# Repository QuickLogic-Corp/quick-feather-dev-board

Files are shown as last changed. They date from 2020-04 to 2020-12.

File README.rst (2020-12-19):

==============================
QuickFeather Development Board
==============================

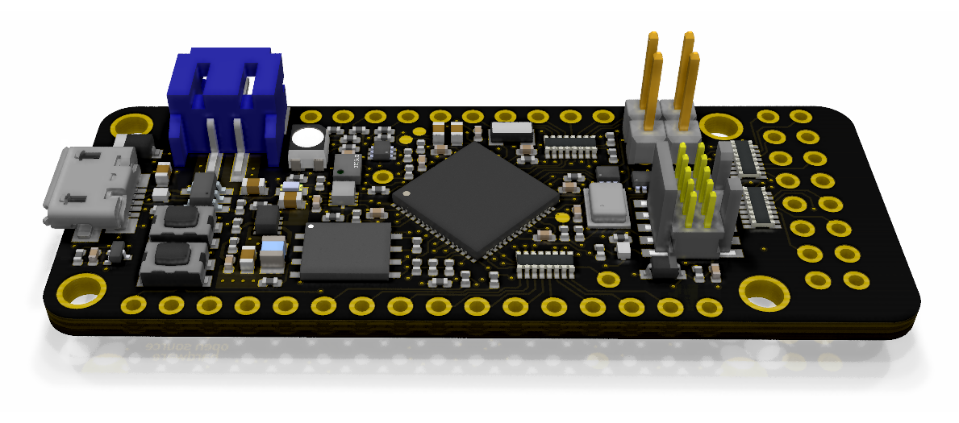
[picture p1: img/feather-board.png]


Overview
========

This repository contains open hardware design files for the `QuickFeather development board <https://www.quicklogic.com/products/eos-s3/quickfeather-development-kit/>`_ based on the QuickLogic `EOS S3 Sensor Processing Platform <https://www.quicklogic.com/products/eos-s3/>`_.
The design files were created by `Antmicro <https://www.antmicro.com>`_ in cooperation with `QuickLogic <https://www.quicklogic.com/>`_.
The board has been designed to keep compatibility with the `Adafruit Feather <https://learn.adafruit.com/adafruit-feather/feather-specification>`_ ecosystem of evaluation boards.
This allows the user to explore functionalities of the EOS S3 platform.

Getting Started
---------------
The  `QuickFeather_UserGuide <https://github.com/QuickLogic-Corp/quick-feather-dev-board/blob/master/doc/QuickFeather_UserGuide.pdf>`_ contains instructions for running the pre-installed example program.

Key features
------------

* QuickLogic EOS S3 Processing Platform
* `mCube MC3635 <https://mcubemems.com/wp-content/uploads/2019/06/MC3635-Datasheet-APS-048-0044v1.6.pdf>`_ accelerometer
* `Infineon DPS310 <https://www.infineon.com/dgdl/Infineon-DPS310-DataSheet-v01_01-EN.pdf?fileId=5546d462576f34750157750826c42242>`_ pressure sensor
* `Infineon IM69D130 <https://www.infineon.com/dgdl/Infineon-IM69D130-DS-v01_00-EN.pdf?fileId=5546d462602a9dc801607a0e46511a2e>`_ MEMS microphone 
* 16Mbit of on-board `flash memory  <http://www.gigadevice.com/datasheet/gd25q16c/>`_
* User button and RGB LED
* Powered from USB or a single Li-Po battery
* Integrated `battery charger <http://ww1.microchip.com/downloads/en/DeviceDoc/20001984g.pdf>`_
* USB data signals tied to programmable logic
* IO signals break-routed into general purpose pinheads
* Compatible with standard 0.1" breadboards

Layout and dimensions
---------------------

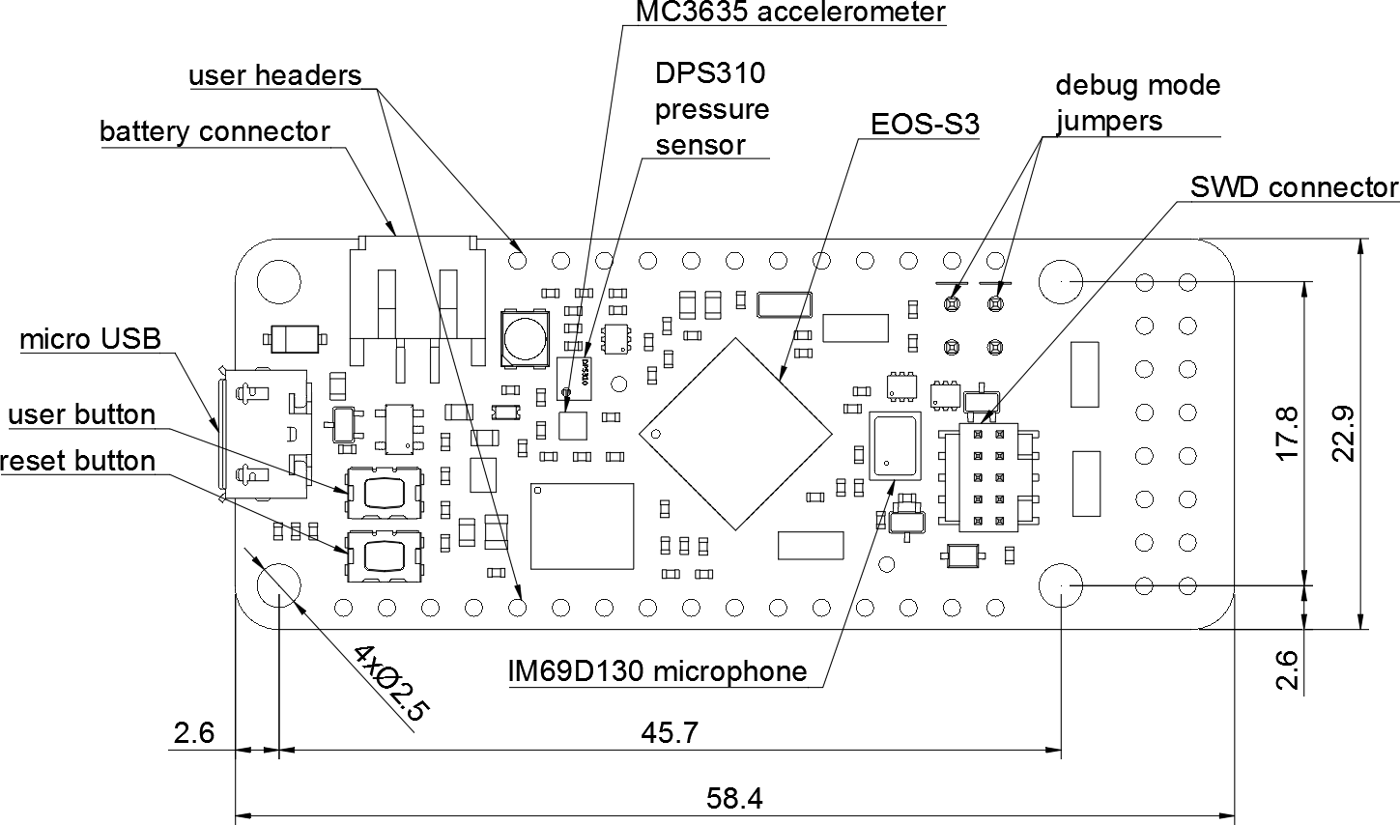
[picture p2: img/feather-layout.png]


Development ecosystem
=====================

Simulation
----------

The board is supported in `Renode <https://renode.io/>`_, the open source simulation framework by Antmicro - you can run a virtual copy of this hardware for software development purposes on your PC. A link to the relevant demo script is provided in Renode's `supported boards section <https://renode.readthedocs.io/en/latest/introduction/supported-boards.html>`_.

Basic Usage
=====================

Simple
----------

Connect the micro-usb port of the board to the PC, which will both provide power to the board as well as offer a virtual USB-CDC UART port out of the box.

Advanced
----------

For using the board with advanced scenarios, such as loading a custom FPGA image, an additional dedicated USB-UART board (for example based on the PL2303, FT232 etc.) needs to be connected to the QuickFeather UART pins, as shown below:
::

      +--------------------------+         +--------------+  
      | QF UART RX(IO_45) [J3.3] +-------->+ USB-UART TX  |  
      |                          |         |              |  
      |                          |         |              |  
      | QF UART TX(IO_44) [J3.2] +-------->+ USB-UART RX  |  
      |                          |         |              |  
      |                          |         |              |  
      | QF GND      (GND) [J3.1] +-------->+ USB-UART GND |  
      +--------------------------+         +--------------+  

Refer to `QuickFeather_UserGuide <https://github.com/QuickLogic-Corp/quick-feather-dev-board/blob/master/doc/QuickFeather_UserGuide.pdf>`_ for further details

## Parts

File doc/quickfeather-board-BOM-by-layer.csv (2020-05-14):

Reference | Quantity | Value | Footprint | Manufacturer | MPN | Layer
C1 C14 C16 C2 C5 | 5 | C_4u7_0603 | 0603-cap | TDK | C1608X5R1V475M080AC | Top
C10 C11 C12 C13 C15 C17 C18 C8 C9 | 9 | C_100n_0402_6V3 | 0402-cap | Walsin | 0402X104K6R3CT | Top
C19 | 1 | C_1u_0402 | 0402-cap | TDK | C1005X6S1A105K050BC | Top
C3 | 1 | C_100p_0402 | 0402-cap | WALSIN | 0402N101J500CT | Top
C4 | 1 | C_22u_0603 | 0603-cap | MURATA | GRM188R60J226MEA0D | Top
C6 C7 | 2 | C_12p_0402 | 0402-cap | TDK | CGA2B2C0G1H120J050BA | Top
D1 | 1 | MBR0520LT1G | SOD-123 | ON Semiconductor | MBR0520LT1G | Top
D11 D3 D5 | 3 | TPD2EUSB30DRTR | SOT-3 | Texas Instruments | TPD2EUSB30DRTR | Top
D2 | 1 | LG_L29K-G2J1-24-Z | LED_0603 | OSRAM Opto Semiconductors Inc. | LG L29K-G2J1-24-Z | Top
D4 | 1 | ASMB-MTB1-0A3A2 | LED-PLCC4_3.2x2.8mm_B | Broadcom | ASMB-MTB1-0A3A2 | Top
D6 | 1 | SD05C.TCT | SOD-323-SD05 | Semtec | SD05C.TCT | Top
IC1 | 1 | EOS-S3-QFN | QFN-64_8.5x8.5_EOS | QuickLogic | EOSA1-S-PUN64 | Top
J1 J7 | 2 | 61300211121 | PinHeader_1x2_P2.54_Drill0.9mm | Wurth Electronic | 61300211121 | Top
J4 | 1 | S2B-PH-SM4-TB_LF__SN_ | PinHeader_2x1mm_P2mm_SMD_RA | JST Sales America Inc. | S2B-PH-SM4-TB(LF)(SN) | Top
J5 | 1 | 0473460001 | USB_Micro_B_Female_0473460001 | Molex | 0473460001 | Top
J6 | 1 | FTSH-105-01-L-DV-K | PinHeader_2x5_P1.27_SMD | Samtec Inc. | FTSH-105-01-L-DV-K | Top
L1 | 1 | DFE201610E-R47M=P2 | 0806 | Murata | DFE201610E-R47M=P2 | Top
MIC1 | 1 | IM69D130 | IM69D130 | Infineon | IM69D130 | Top
Q1 | 1 | NX3008CBKV | SOT-563 | Nexperia | NX3008CBKV | Top
Q2 Q3 | 2 | 2N7002PV | SOT-563 | Nexperia | 2N7002PV | Top
Q4 | 1 | DMG1012T-7 | SOT-523 | Diodes Incorporated | DMG1012T-7 | Top
R1 | 1 | R_1M5_0402 | 0402-res | Multicomp | MCWR04W1504FTL | Top
R10 R14 R15 R19 R23 R31 R32 R34 R37 R6 R8 | 11 | R_10k_0402 | 0402-res | VISHAY | CRCW040210K0FKEDHP | Top
R11 R28 R29 R38 R39 R40 R7 | 7 | R_22R_0402 | 0402-res | VISHAY | CRCW040222R0FKED | Top
R12 R17 R5 | 3 | R_100k_0402 | 0402-res | VISHAY | CRCW0402100KFKEDHP | Top
R13 R24 R26 | 3 | R_100R_0402 | 0402-res | BOURNS | CR0402-FX-1000GLF | Top
R16 | 1 | R_200k_0402 | 0402-res | YAGEO_(PHYCOMP) | RC0402FR-07200KL | Top
R18 R2 R20 | 3 | R_4k7_0402 | 0402-res | PANASONIC_ELECTRONIC_COMPONENTS | ERJ2GEJ472X | Top
R25 | 1 | R_220R_0402 | 0402-res | Stackpole Electronics Inc | RMCF0402JT220R | Top
R27 R3 R9 | 3 | R_1k5_0402 | 0402-res | PANASONIC_ELECTRONIC_COMPONENTS | ERJ2RKF1501X | Top
R30 R33 R41 | 3 | EXB2HV220JV | R_Array_Convex_8x0602 | Panasonic | EXB2HV220JV | Top
R4 | 1 | R_453k_0402 | 0402-res | VISHAY | CRCW0402453KFKED | Top
S1 S2 | 2 | KMR2 | SW_SPST_4.2x2.8 | C&K Components | KMR211NGLFS | Top
U1 | 1 | TPS62821DLCR | QFN-8_2x1mm | Texas Instruments | TPS62821DLCR | Top
U2 | 1 | MCP73831T-2ACI_OT | SOT-753 | Microchip Technology | MCP73831T-2ACI/OT | Top
U3 | 1 | GD25Q16CWIGR | GD25Q16CWIG | GigaDevice | GD25Q16CWIGR | Top
U4 | 1 | DPS310 | PG-VLGA-8-2 | Infineon | DPS310 | Top
U5 | 1 | MC3635 | MC3635 | mCube | MC3635 | Top
X1 | 1 | ECS-_327-12_5-34B-TR | SMD-2_3.2x1.5mm | ECS Inc. | ECS-.327-12.5-34B-TR | Top
J2 | 1 | 1x12_pinhead | 1x12_pinhead |  |  | DNP
J3 | 1 | 1x16_pinhead | 1x16_pinhead |  |  | DNP
J8 | 1 | 2x8_pinhead | 2x8_pinhead |  |  | DNP
R21 R22 R36 | 3 | R_10k_0402 | 0402-res | VISHAY | CRCW040210K0FKEDHP | DNP
R42 | 1 | EXB2HV220JV | R_Array_Convex_8x0602 | Panasonic | EXB2HV220JV | DNP
M1 M2 M3 M4 | 4 | mounting_pad | mpad |  |  | Virtual
N1 | 1 | oshw_logo | oshw-logo |  |  | Virtual
N2 | 1 | ql_logo | LOGO |  |  | Virtual
TP1 TP2 TP6 | 3 | TP_SMD1MM | Testpoint_smd_1mm | N/A | N/A | Virtual
TP4 TP5 | 2 | TP_THT | Testpoint_THT_Drill0.9mm | N/A | N/A | Virtual

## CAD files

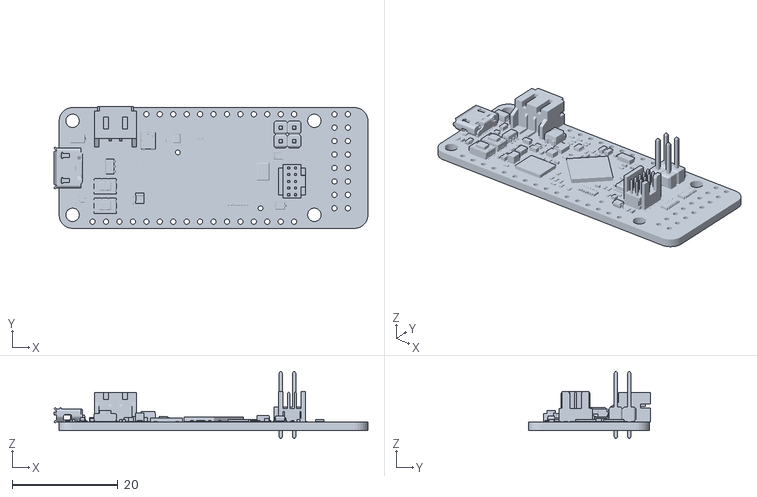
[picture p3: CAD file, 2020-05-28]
3Dmodels/quickfeather-board.stl
59.4 x 23.0 x 12.7

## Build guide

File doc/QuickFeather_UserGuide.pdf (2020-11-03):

# QuickFeather Low Power MCU Open Source Hardware

## Development Kit User Guide (Rev 1.2.1)

This document serves as a guide for the user to getting started with the QuickFeather revision 1.2 board.

This guide provides users with functional descriptions, configuration options for the QuickFeather Low Power MCU Open

Source Hardware Development Kit Rev 1.2. It also serves as a “Getting Started” and “How To” guide.

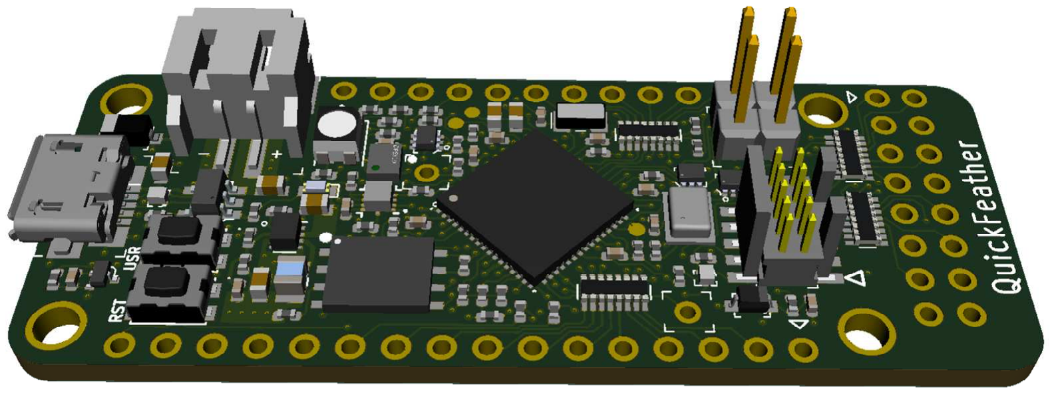
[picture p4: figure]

Figure 1: QuickFeather Low Power MCU Open Source Hardware Development Kit

## QuickFeather Low Power MCU Open Source Hardware Development Kit Overview

The QuickFeather Low Power MCU Open Source Hardware Development Kit (HDK) is a small form factor system ideal for enabling the next generation of low-power Machine Learning (ML) capable IoT devices. Unlike other development kits which are based on proprietary hardware and software tools, QuickFeather is based on 100% open source hardware, compatible with the Adafruit Feather form factor, and is built around 100% open source software (including the Symbiflow FPGA Tools).

The QuickFeather HDK is powered by QuickLogic’s EOS™ S3 (https://www.quicklogic.com/products/eos-s3/), the first eFPGA-enabled Arm CortexⓇ-M4F MCU to be fully supported with Zephyr RTOS and FreeRTOS. Other functionality

includes:

- QuickLogic EOS S3 MCU Platform
- mCube MC3635 accelerometer
- Infineon DPS310 pressure sensor
- Infineon IM69D130 MEMS microphone
- 16Mbit of on-board flash memory
- User button and RGB LED
- Powered from USB or a single Li-Po battery

- Integrated battery charger
- USB data signals tied to programmable logic
- IO signals break-routed into general purpose pinheads
- Compatible with standard 0.1" breadboards

Benefits

- QuickFeather HDK is small, Feather compatible, inexpensive, and is 100% supported by open source tools.
- With a Cortex M4F MCU and integrated eFPGA, the EOS S3 lets you innovate with 100% open source hardware and software.

Applications

- Tiny ML applications (such as with SensiML’s AI Software Platform and Google’s TensorFlow Lite)
- General purpose MCU applications

## Getting Started

What You Need

- 1 × QuickFeather HDK Rev 1.2 development board
- 1 x Micro-USB 2.0 cable¹
, Type A to Micro B for Power
- Laptop (Win10 OS²
or Linux OS) running terminal program (such as PuTTY³ or any UART console
application)

Note¹, 2:

1
you will need to provide your own USB cable

2
Windows 7 and Windows 8 are not supported

3
PuTTY download & installation: https://www.putty.org/

Running pre-loaded program from Flash

The purpose of the pre-loaded program is to make it very fast and straightforward for a new user to verify the board is functioning correctly. While we do production testing of every QuickFeather HDK before we ship, sometimes things happen during shipping or storage. Running this test takes less than a minute to do, requires no knowledge of the HDK, and will give you peace of mind the HDK is ready for you to start innovating freely.

1. Make sure there is no shunt installed at J7 and J1; if there are shunts installed, remove the shunts; save the shunts for future firmware development
2. Provide power to the QuickFeather HDK using the micro USB cable; the power source can be either a PC or wall adapter. When there is power applied to the board, the LED flashes “white” for a short duration

### 3. Press the “reset” button

### 4. The LED flashes blue color for 5 seconds and then turns off

### 5. Wait for 5 seconds

### 6. On Windows 10 machine, open Device Manager to check for the assign COM port

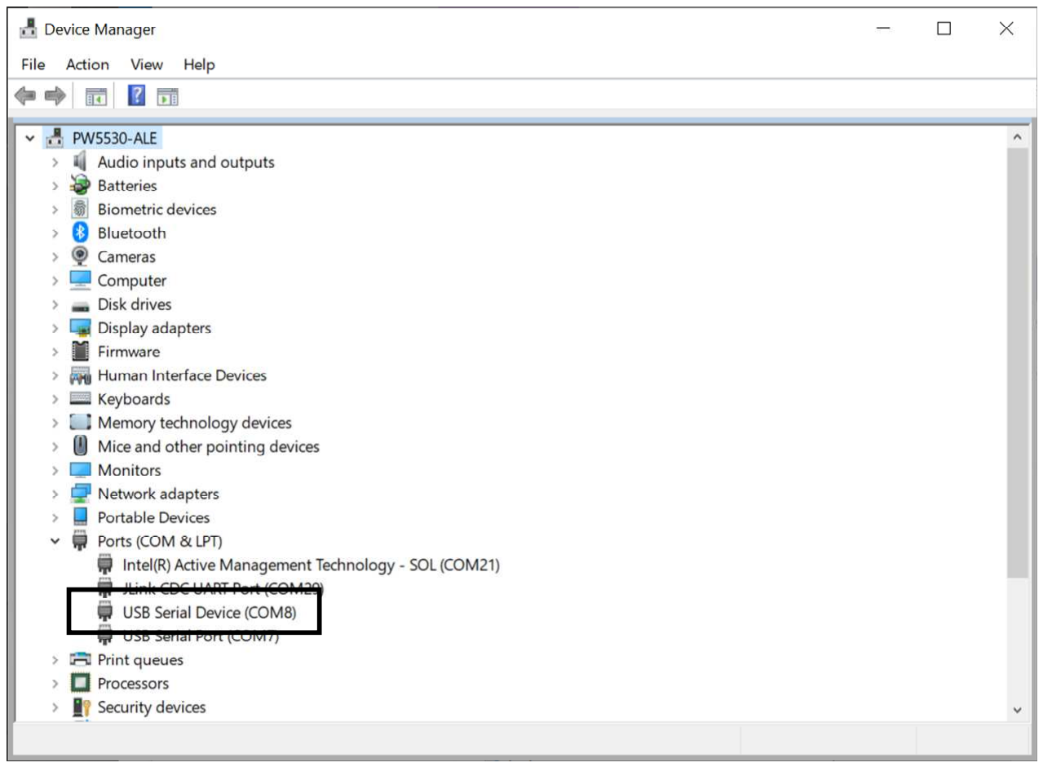
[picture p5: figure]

Figure 2: Checking COM Port with Device Manager

Note: for Win10 system, the system device manager may not fully configure QuickFeather as COM port when install for the first time, repeat step (3) to (6).

### 7. Launch PuTTY application and configure for Serial access and select “Open”

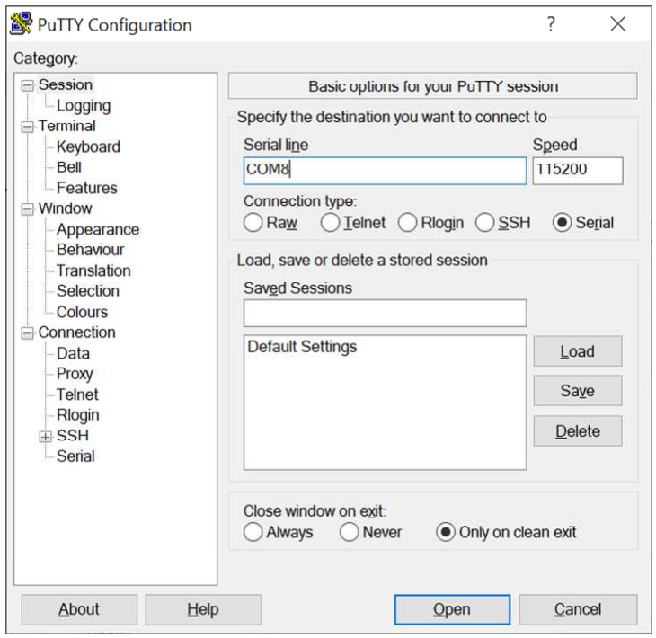
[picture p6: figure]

Figure 3: Checking COM Port with Device Manager

### 8. Perform the followings in the PuTTY terminal:

a) Type: “diag” to bring up QuickFeather diagnostic menu
b) Type: “help” to bring up the menu of commands
c) Type: “red”; the command shows red color for LED
d) Type: “red”; the LED turns off the LED
e) Try “green” and “blue” command

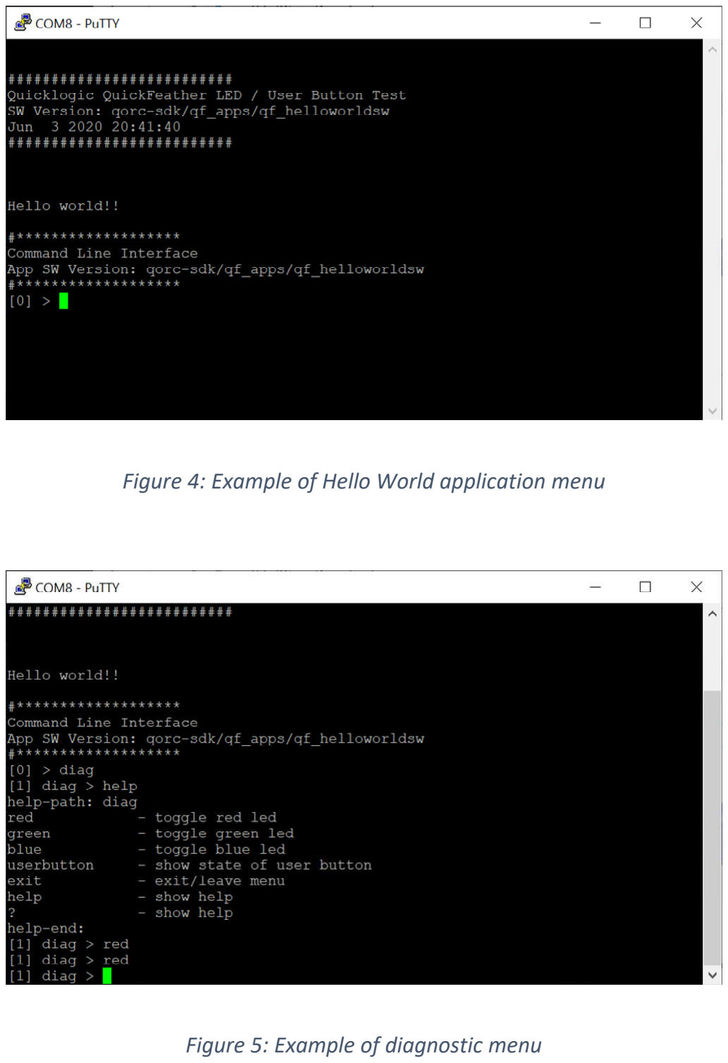
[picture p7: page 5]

Figure 4: Example of Hello World application menu

Figure 5: Example of diagnostic menu

## Board Layout Overview

Components on the Board

- QuickLogic EOS S3 MCU Platform
- mCube MC3635 accelerometer
- Infineon DPS310 pressure sensor
- Infineon IM69D130 MEMS microphone
- 16Mbit of on-board flash memory
- User button and RGB LED
- Hardware Reset button
- Powered from USB or a single Li-Po battery
- Integrated battery charger
- USB data signals tied to programmable logic
- IO signals break-routed into general purpose pinheads

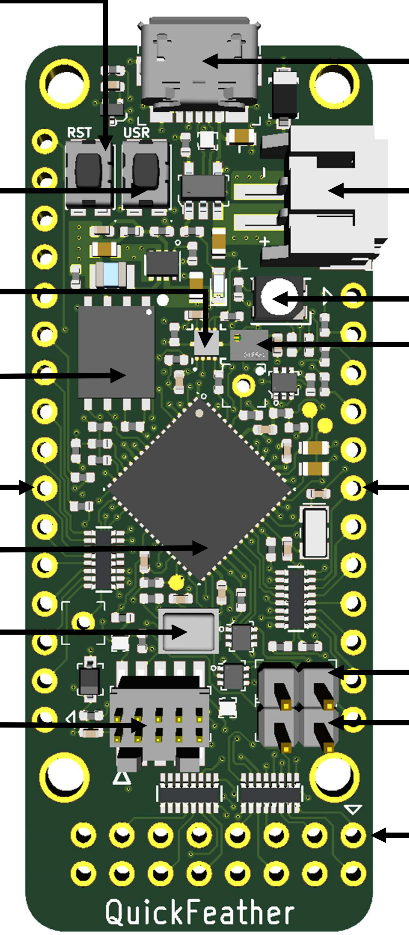
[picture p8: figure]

Figure 6: QuickFeather HDK Board Layout Overview

## IO Expansion Connectors

EOS S3 MCU IO Map

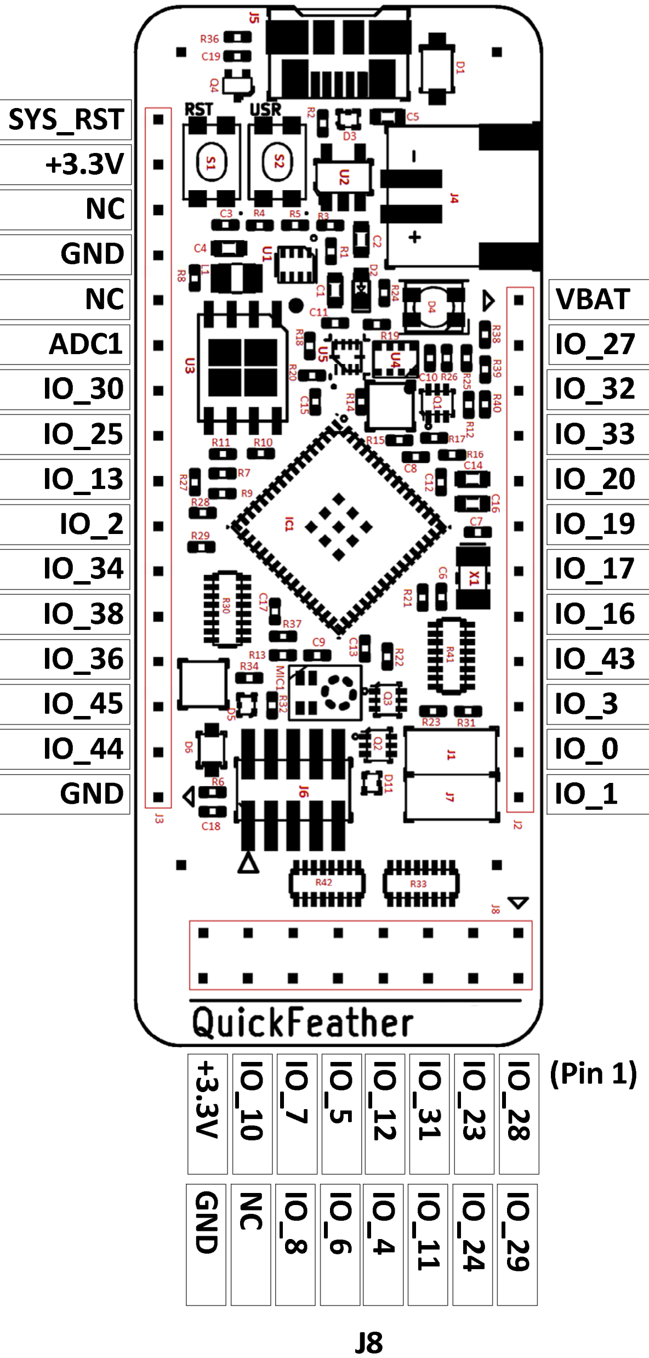
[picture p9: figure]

Figure 7: QuickFeather HDK IO Expansion connectors

EOS S3 MCU IO | QuickFeather HDK Function | Additional Function | Expansion
IO_0 | I2C0 SCL | | J2.11
IO_1 | I2C0 SDA | | J2.12
IO_2 | IO | | J3.7
IO_3 | Accelerometer MC3635 interrupt | | J2.10
IO_4 | IO | | J8.8
IO_5 | IO | | J8.9
IO_6 | User Button input | | J8.10
IO_7 | IO | | J8.11
IO_8 | IO | | J8.12
IO_10 | IO | | J8.13
IO_11 | IO | | J8.6
IO_12 | IO | | J8.7
IO_13 | IO | | J3.8
IO_14 | Serial Wire Debug CLK | | J6.4
IO_15 | Serial Wire Debug DATA | | J6.2
IO_16 | IO | SPI Slave CLK | J2.8
IO_17 | IO | SPI Slave MISO (input) | J2.7
IO_18 | Blue LED | | N/A
IO_19 | IO | SPI Slave MOSI | J2.6
IO_20 | IO | SPI Slave CSn | J2.5
IO_21 | Green LED | | N/A
IO_22 | Red LED | | N/A
IO_23 | IO | I2S Slave WCLK (frame) | J8.3
IO_24 | IO | I2S Slave DATA (dout) | J8.4
IO_25 | IO | | J3.9
IO_27 | IO | SPI Master CS2 | J2.2
IO_28 | PDM Data; to isolate, remove R13 | | J8.1
IO_29 | PDM CKO | | J8.2
IO_30 | IO | | J3.10
IO_31 | IO | I2S Slave CLK (input) | J8.5
IO_32 | IO | | J2.3
IO_33 | IO | | J2.4
IO_34 | SPI Master CLK | | J3.6
IO_36 | SPI Master MISO | | J3.4
IO_38 | SPI Master MOSI (flash) | | J3.5
IO_40 | IO | | N/A
IO_43 | IO | Interrupt output to Host | J2.9
IO_44 | IO | UART TX | J3.2
IO_45 | IO | UART RX | J3.3

Connector J2

J2 | EOS S3 MCU IO | QFN Pin# | Function

1 VBAT
2 | IO_27 | 28 | IO; SPI Master CS2n
3 | IO_32 | 22 | IO; I2C bus 1 SDA
4 | IO_33 | 21 | IO; I2C bus 1 SCL
5 | IO_20 | 37 | SPI Slave SSn input; EOS S3 boot-strap
6 | IO_19 | 36 | SPI Slave MOSI input; EOS S3 boot-strap
7 | IO_17 | 42 | SPI Slave MISO output
8 | IO_16 | 40 | SPI Slave CLK input
9 | IO_43 | 7 | EOS S3 Interrupt output
10 | IO_3 | 2 | MC3635 Interrupt input
11 | IO_0 | 4 | I2C0 SCL
12 | IO_1 | 5 | I2C0 SDA

Connector J3

J3 | EOS S3 MCU IO | QFN Pin# | Function

1 Ground
2 | IO_44 | 8 | S3 UART TX
3 | IO_45 | 9 | S3 UART RX
4 | IO_36 | 17 | SPI Master MISO input
5 | IO_38 | 16 | SPI Master MOSI output
6 | IO_34 | 20 | SPI Master CLK output
7 | IO_2 | 6 | IO
8 | IO_13 | 55 | IO
9 | IO_25 | 31 | IO
10 | IO_30 | 25 | IO
11 | ADC1 | 47 | ADC1 input
12 No Connect
13 Ground
14 No Connect
15 +3.3V
16 | SYS_RSTn | 41 | EOS S3 HW reset input

Connector J8

J8 | EOS S3 MCU IO | QFN Pin# | Function
1 | IO_28 | 27 | PDM microphone Data
2 | IO_29 | 26 | PDM microphone CLK
3 | IO_23 | 33 | I2S Slave WCLK input
4 | IO_24 | 32 | I2S Slave DATA output
5 | IO_31 | 23 | I2S Slave CLK input
6 | IO_11 | 57 | IO
7 | IO_12 | 56 | IO
8 | IO_4 | 3 | IO
9 | IO_5 | 64 | IO
10 | IO_6 | 62 | User button input
11 | IO_7 | 63 | IO
12 | IO_8 | 61 | IO
13 | IO_10 | 59 | IO
14 No Connect
15 +3.3V
16 Ground

## Development connector

EOS S3 MCU SWD connector

J6 | EOS S3 MCU IO | Function

1 +3.3V
2 | IO_15 | SWD IO
3 Ground
4 | IO_14 | SWD CLK
5 Ground
6 No Connect
7 No Connect
8 No Connect
9 Ground
10 | SYS_RSTn | Hardware Reset

Boot-strap IO_19 & IO_20

- Install both shunts to use SWD Debugger for development
- Remove both shunts for boot-from-flash

Note: QuickFeather HDK board flash device must contain valid boot image for successful boot from flash.

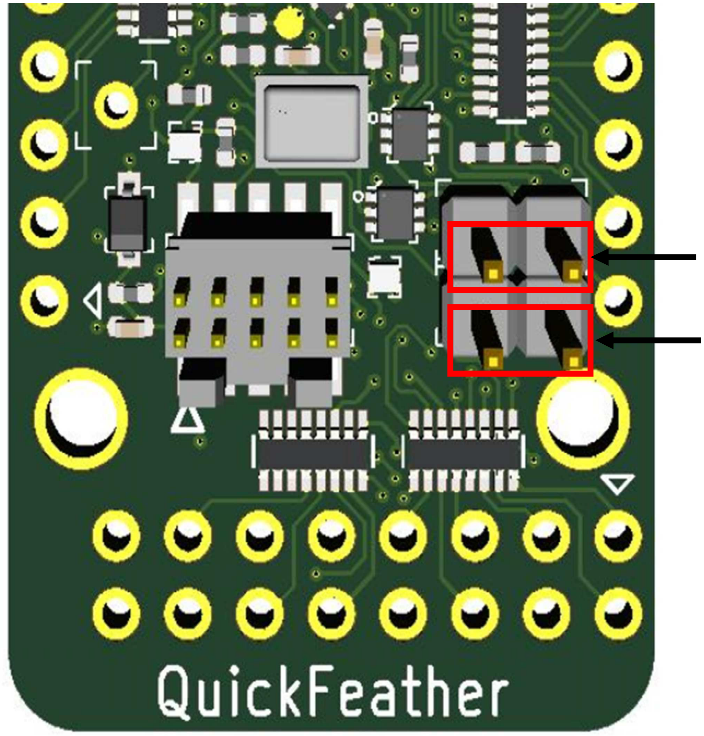
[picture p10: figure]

Figure 8: Boot strap J1 and J7

## QuickFeather HDK power supplies

There are two ways to provide power to the QuickFeather HDK: USB connector (J5) or Battery connector (J4).

When both ports are connected at the same time, the USB power activates the battery charging circuit that provide charging current to the battery.

When using a rechargeable battery, the minimum input voltage will determine the maximum currents that the system needs to support. This is important when connecting additional peripherals to the QuickFeather HDK that also requires connection to +3.3V for supplies.

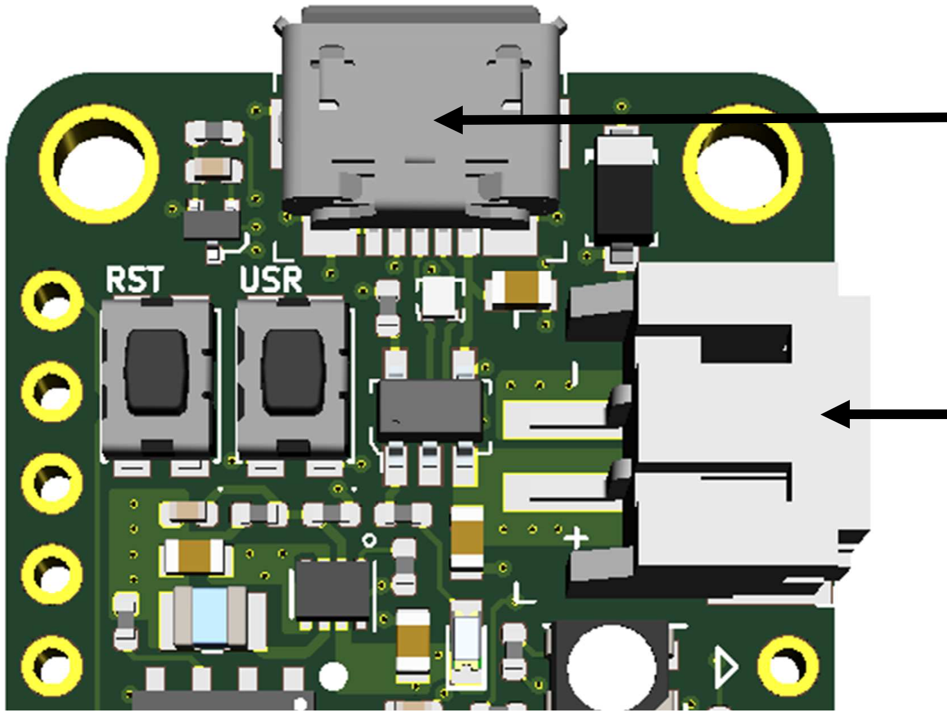
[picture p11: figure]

Figure 9: QuickFeather HDK Power inputs

## Connecting additional Peripherals to the QuickFeather HDK

QuickLogic’s QuickFeather supports direct connection to FeatherWing module (providing that the FeatherWing module has Stack Headers installed) via expansion connector J2 and J3. Refer to Adafruit web site for additional information on available FeatherWing modules.

Sensor with I2C port

QuickFeather board supports connecting to sensor module with I2C slave interface via expansion connectors J2. QuickFeather I2C supports I2C Standard mode (100KHz) and Fast mode (400KHz). There are two I2C buses available:

- I2C0 bus: J2 pin 12 (SDA) and J2 pin 11 (SCL); the signals (SCL and SDA) are connected to 4.7KΩ pull-up resistor.

This bus is shared with onboard I2C sensors: Accelerometer MC3635 (address 0x44h) and Pressure DPS310 (address 0x77h).
- I2C1 bus: J2 pin 3 (SDA) and J2 pin 4 (SCL); there is no pull up resistor on the I2C1 bus.

Steps to connect external I2C sensors to QuickFeather board:

- Ground connection
- Power connection (+3.3V supplies); check supply voltage level meeting connecting module requirement
- Connect SCL and SDA signals; check IO level (> +3.0V IO only)
- Keep connecting wires as short as possible
- Configure the I2C address to avoid address 0x44h (on-board ACCEL MC3635) and address 0x77h (on-board

Pressure sensor DPS310)
- Check SCL and SDA rise time (< 1000 ns for Standard mode and < 300 ns for Fast mode)

Note: refer to I2C- bus specification for details (UM10204)

Sensor with SPI Slave port

QuickFeather board supports connecting to sensor module with SPI slave interface via expansion connectors J2 and J3: SPI MASTER CLK (J3 pin 6), SPI MASTER MISO (J3 pin 4), SPI MASTER MOSI (J3 pin 5) and SPI MASTER SS2 (J2 pin 2). The maximum supported SPI clock frequency is 10MHz.

Steps to connect external SPI sensor to QuickFeather board:

- Ground connection
- Power connection (+3.3V supplies check supply voltage level meeting connecting module requirement
- Connect SPI MASTER signals; check IO level (> +3.0V IO only)
- Keep connecting wires as short as possible
- Check signal quality using scope

PDM Microphones

Single PDM microphone

The on-board PDM microphone (Infineon IM69D130) is configured as left channel output (driving active data on falling edge of PDM CLK). QuickFeather supports external PDM microphone connection via expansion connector J8: PDM CLK (J8 pin 2) and PDM DATA (J8 pin 1).

Steps to connect one external PDM microphone to QuickFeather board:

- Ground connection
- Power connection (+3.3V supplies check supply voltage level meeting connecting module requirement
- Connect PDM CLK and PDM DATA signals; check IO level (> +3.0V IO only)
- Keep connecting wires as short as possible
- PDM microphone is configured as right channel microphone; the L/R signal or Channel signal is connected to

VDD
- Check signal quality using scope

Two PDM microphones

To support two external PDM microphones configuration, it is required to disable the connection of the on-board PDM microphone.

QuickFeather supports external PDM microphone connection via expansion connector J8: PDM CLK (J8 pin 2) and PDM DATA (J8 pin 1).

Steps to connect two external PDM microphones to QuickFeather board:

- Ground connection
- Power connection (+3.3V supplies check supply voltage level meeting connecting module requirement
- Remove R13 (100Ω resistor)
- Connect PDM CLK and PDM DATA signals; check IO level (> +3.0V IO only)
- Keep connecting wires as short as possible; avoid star connection scheme (see figure below)
- Configure one PDM microphone as left channel and one PDM microphone as right channel
- Check signal quality using scope

R13

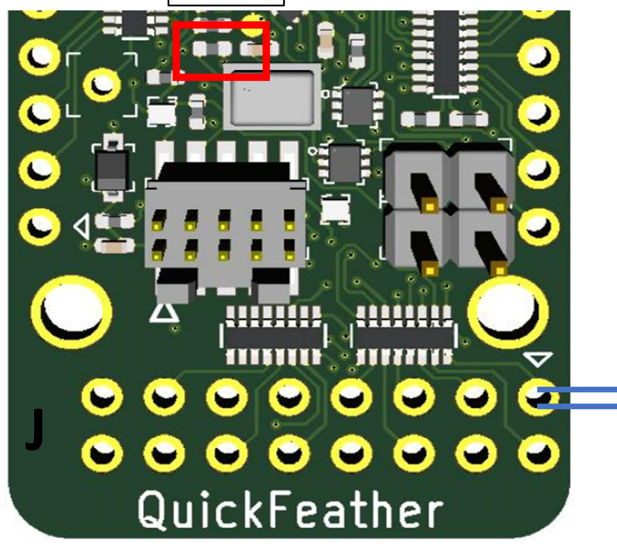
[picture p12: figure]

Figure 10: Microphones Wiring recommendation

## Download Binaries using Jlink SWD

QuickFeather supports loading and testing stand-alone eFPGA design or eFPGA + M4 MCU design, using SWD standard tool such as Segger’s Jlink SWD or OCD. Below are the instructions for system with Windows 10 OS with Segger Jlink pod

What you need
- Laptop or PC with Windows 10
- Segger Jlink pod and PC connecting USB cable
- Segger Jlink adapter to 10-pin connector and cable
- QuickFeather board and micro USB cable

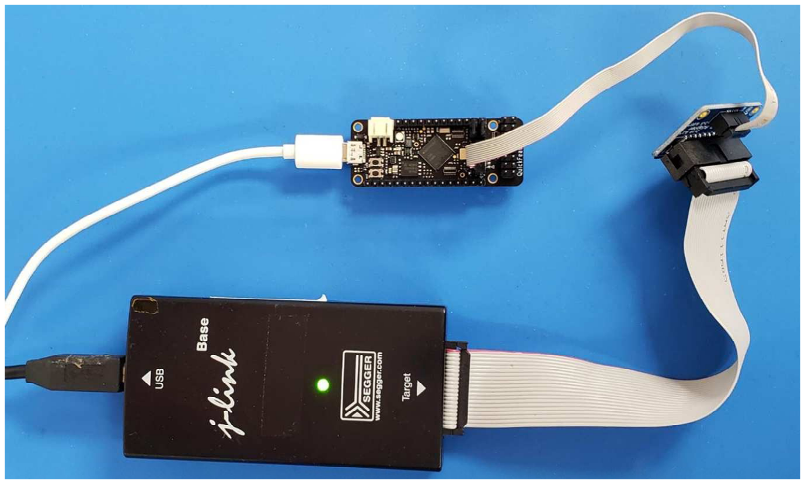
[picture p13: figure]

Figure 11: Jlink to QuickFeather connection

Download stand-alone FPGA binaries instructions
- Disconnect QuickFeather power; if USB-to-Serial cable connected to the board, remove the connection from PC
- Install shunts at QuickFeather J1 and J7
- Connect micro USB cable from QuickFeather to PC
- Connect 10-pin cable to QuickFeather connector J6; check connector key for correct alignment
- Press reset button
- Open CMD console
- Type: “Jlink.exe -device cortex-m4 -If SWD -speed 4000 -commandFile "Jlink script"

Note:
- Jlink.exe: Link commander – include reference to the location of executable
- Jlink script: output file symbiflow for EOS S3 FPGA binaries
- Refer to Jlink Commander for more additional information

Download FPGA binaries + M4 MCU binaries instructions
- Disconnect QuickFeather power; if USB-to-Serial cable connected to the board, remove the connection from PC

- Install shunts at QuickFeather J1 and J7
- Connect micro USB cable from QuickFeather to PC
- Connect 10-pin cable to QuickFeather connector J6; check connector key for correct alignment
- Press reset button
- Open CMD console (#1)
- Launch Jlink commander (i.e. type “Jlink.exe”) and follow the on-screen instructions to connect to QuickFeather

M4 target
- Execute the followings in Link Commander console
- Type: “r” to reset the EOS S3
- Type: “loadbin m4_application.bin 0x0”
- Type: “r”
- Open another CMD console (#2)
- Type: “Jlink.exe -device cortex-m4 -If SWD -speed 4000 -commandFile "Jlink script"

Note:
- Jlink.exe: Link commander – include reference to the location of executable
- Jlink script: Symbiflow’s output for EOS S3 FPGA binaries
- Refer to Jlink Commander for more additional information
- Return to console #1; type: “g”; the M4 binaries in M4 SRAM will start to run and the eFPGA is configured

## Revision

Version | Date | Revision
1.0 | June 2020 | First release.
1.1 | June 2020 | Update with Hello World application figures
1.2 | June 2020 | Update with instruction to use Jlink to download: • FPGA binaries • FPGA + M4 binaries
1.21 | November 2020 | Add R13 location (Figure 10)

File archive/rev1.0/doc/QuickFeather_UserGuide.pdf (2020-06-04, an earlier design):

# QuickFeather Low Power MCU Open Source Hardware

## Development Kit User Guide (Rev 1.0)

This document serves as a guide for the user to getting started with the QuickFeather revision 1.2 board.

This guide provides users with functional descriptions, configuration options for the QuickFeather Low Power MCU Open Source Hardware Development Kit Rev 1.2. It also serves as a “Getting Started” and “How To” guide.

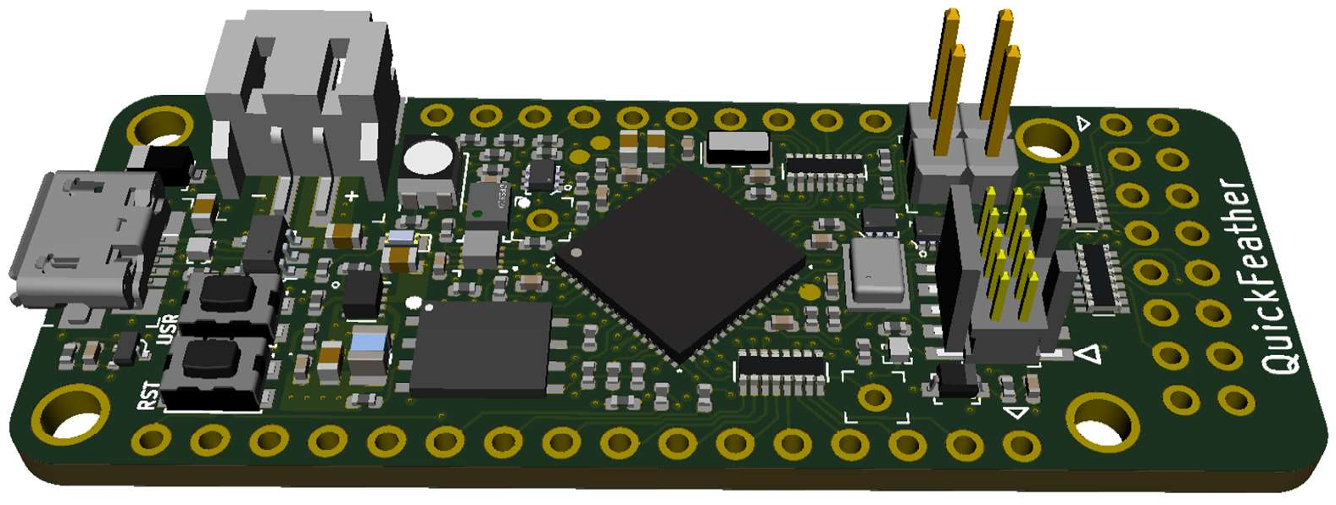
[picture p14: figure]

Figure 1: QuickFeather Low Power MCU Open Source Hardware Development Kit

## QuickFeather Low Power MCU Open Source Hardware Development Kit Overview

The QuickFeather Low Power MCU Open Source Hardware Development Kit (HDK) is a small form factor system ideal for enabling the next generation of low-power Machine Learning (ML) capable IoT devices. Unlike other development kits which are based on proprietary hardware and software tools, QuickFeather is based on 100% open source hardware, compatible with the Adafruit Feather form factor, and is built around 100% open source software (including the Symbiflow FPGA Tools).

The QuickFeather HDK is powered by QuickLogic’s EOS™ S3 (https://www.quicklogic.com/products/eos-s3/), the first eFPGA-enabled Arm CortexⓇ-M4F MCU to be fully supported with Zephyr RTOS and FreeRTOS. Other functionality includes:

- QuickLogic EOS S3 MCU Platform
- mCube MC3635 accelerometer
- Infineon DPS310 pressure sensor
- Infineon IM69D130 MEMS microphone
- 16Mbit of on-board flash memory
- User button and RGB LED
- Powered from USB or a single Li-Po battery

- Integrated battery charger
- USB data signals tied to programmable logic
- IO signals break-routed into general purpose pinheads
- Compatible with standard 0.1" breadboards

### Benefits

- QuickFeather HDK is small, Feather compatible, inexpensive, and is 100% supported by open source tools.
- With a Cortex M4F MCU and integrated eFPGA, the EOS S3 lets you innovate with 100% open source hardware and software.

### Applications

- Tiny ML applications (such as with SensiML’s AI Software Platform and Google’s TensorFlow Lite)
- General purpose MCU applications

## Getting Started

### What You Need

- 1 × QuickFeather HDK Rev 1.2 development board
- 1 x Micro-USB 2.0 cable¹
, Type A to Micro B for Power
- Laptop (Win10 OS²

or Linux OS) running terminal program (such as PuTTY³ or any UART console
application)

Note¹, 2:

1
you will need to provide your own USB cable

2
Windows 7 and Windows 8 are not supported

3
PuTTY download & installation: https://www.putty.org/

### Running pre-loaded program from Flash

The purpose of the pre-loaded program is to make it very fast and straightforward for a new user to verify the board is functioning correctly. While we do production testing of every QuickFeather HDK before we ship, sometimes things happen during shipping or storage. Running this test takes less than a minute to do, requires no knowledge of the HDK, and will give you peace of mind the HDK is ready for you to start innovating freely.

1. Make sure there is no shunt installed at J7 and J1; if there are shunts installed, remove the shunts; save the shunts for future firmware development
2. Provide power to the QuickFeather HDK using the micro USB cable; the power source can be either a PC or wall adapter. When there is power applied to the board, the LED flashes “white” for a short duration

### 3. Press the “reset” button 4. The LED flashes blue color for 5 seconds and then turns off 5. Wait for 5 seconds 6. On Windows 10 machine, open Device Manager to check for the assign COM port

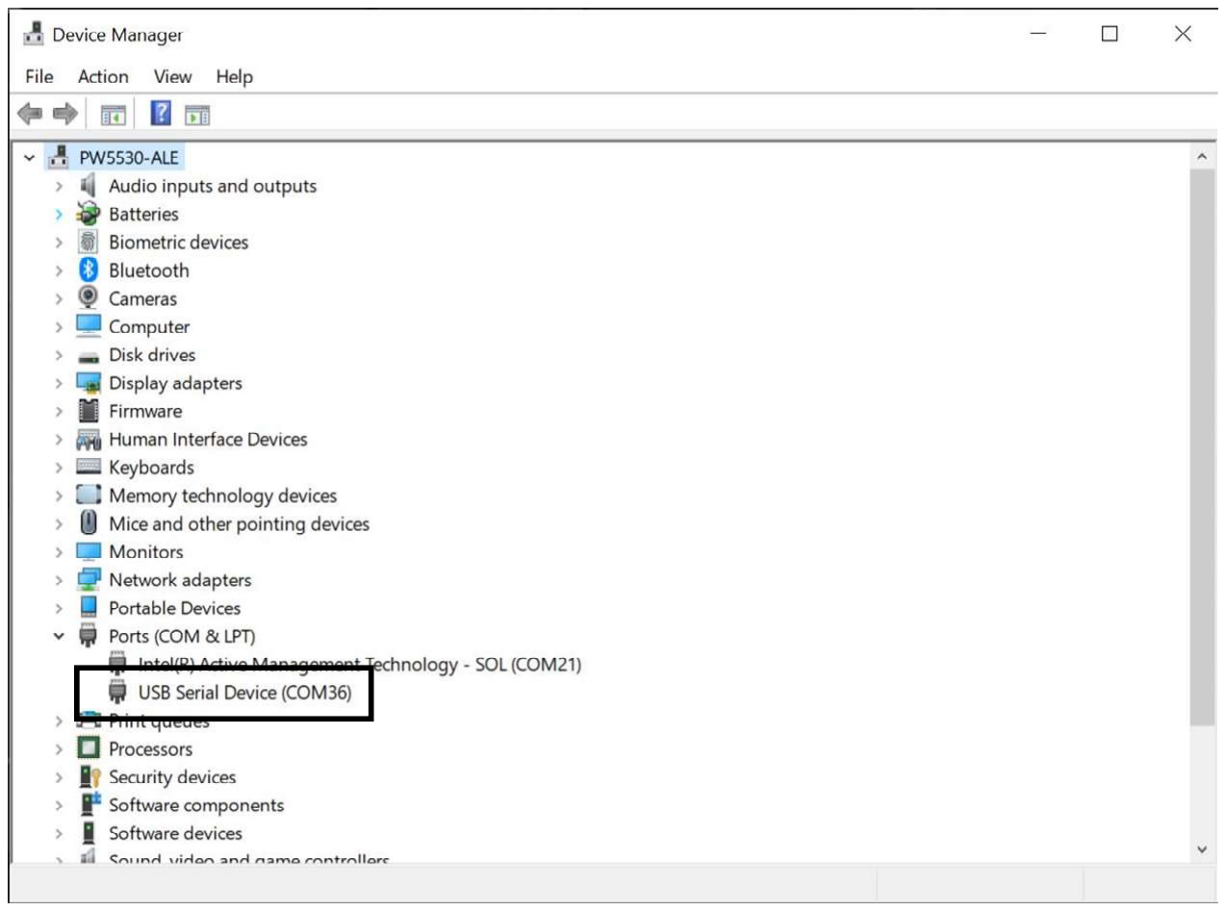
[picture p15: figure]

Figure 2: Checking COM Port with Device Manager

Note: for Win10 system, the system device manager may not fully configure QuickFeather as COM port when install for the first time, repeat step (3) to (6).

### 7. Launch PuTTY application and configure for Serial access and select “Open”

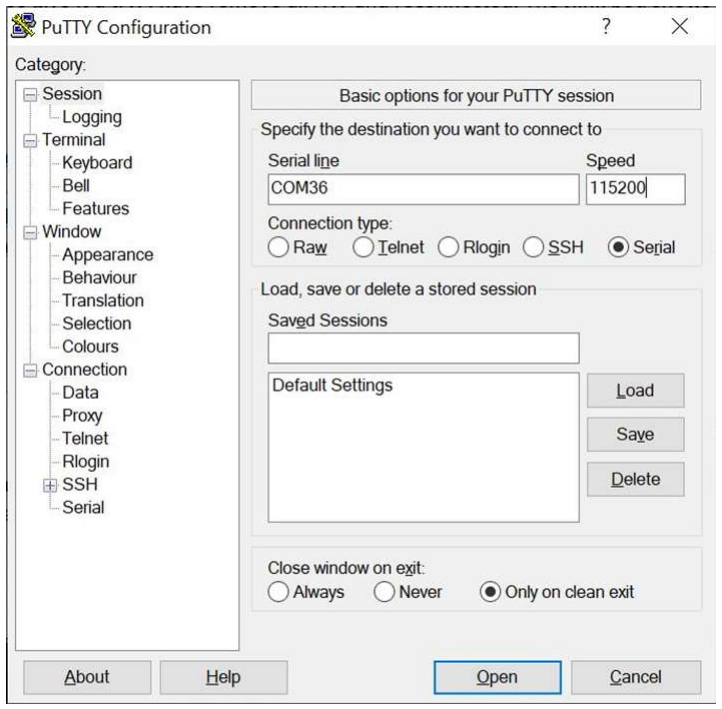
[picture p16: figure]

Figure 3: Checking COM Port with Device Manager

### 8. Perform the followings in the PuTTY terminal:

a) Type: “diag” to bring up QuickFeather diagnostic menu
b) Type: “help” to bring up the menu of commands
c) Type: “red”; the command shows red color for LED
d) Type: “red”; the LED turns off the LED
e) Try “green” and “blue” command

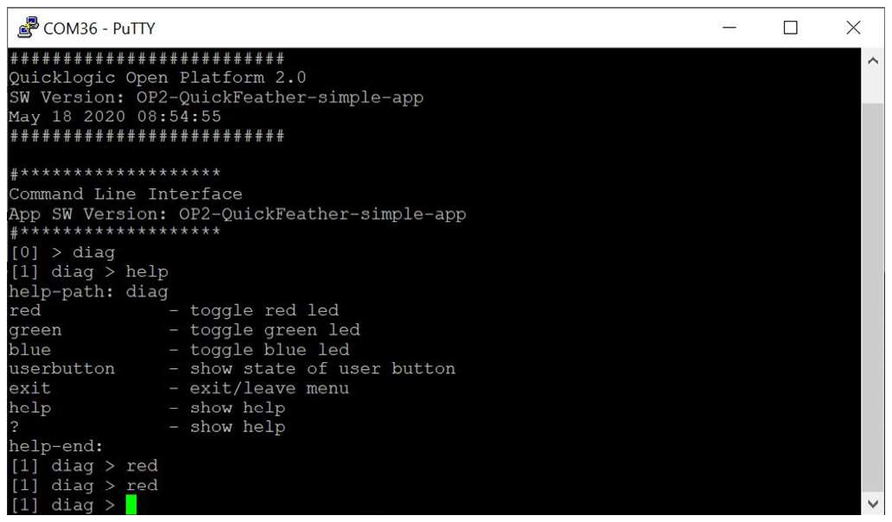
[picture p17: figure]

Figure 4: Example of diagnostic menu

## Board Layout Overview

### Components on the Board

- QuickLogic EOS S3 MCU Platform
- mCube MC3635 accelerometer
- Infineon DPS310 pressure sensor
- Infineon IM69D130 MEMS microphone
- 16Mbit of on-board flash memory
- User button and RGB LED
- Hardware Reset button
- Powered from USB or a single Li-Po battery
- Integrated battery charger
- USB data signals tied to programmable logic
- IO signals break-routed into general purpose pinheads

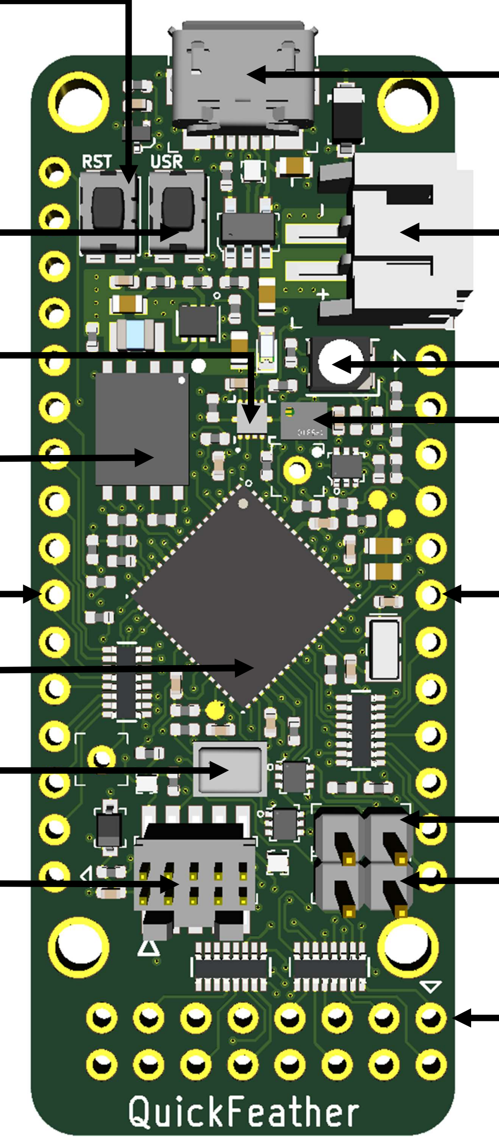
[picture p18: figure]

Figure 5: QuickFeather HDK Board Layout Overview

## IO Expansion Connectors

### EOS S3 MCU IO Map

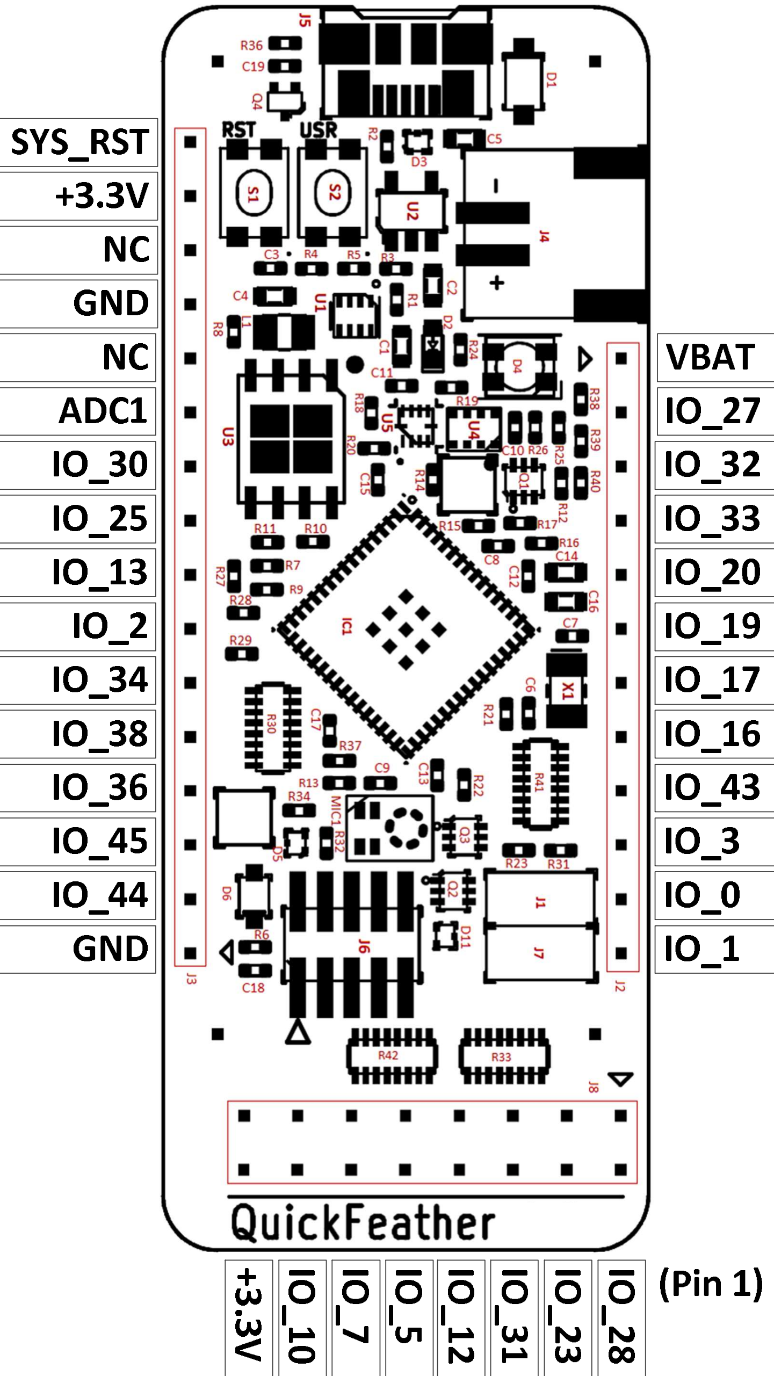
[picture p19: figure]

Figure 6: QuickFeather HDK IO Expansion connectors

EOS S3 MCU IO | QuickFeather HDK Function | Additional Function | Expansion
IO_0 | I2C0 SCL | | J2.11
IO_1 | I2C0 SDA | | J2.12
IO_2 | IO | | J3.7
IO_3 | Accelerometer MC3635 interrupt | | J2.10
IO_4 | IO | | J8.8
IO_5 | IO | | J8.9
IO_6 | User Button input | | J8.10
IO_7 | IO | | J8.11
IO_8 | IO | | J8.12
IO_10 | IO | | J8.13
IO_11 | IO | | J8.6
IO_12 | IO | | J8.7
IO_13 | IO | | J3.8
IO_14 | Serial Wire Debug CLK | | J6.4
IO_15 | Serial Wire Debug DATA | | J6.2
IO_16 | IO | SPI Slave CLK | J2.8
IO_17 | IO | SPI Slave MISO (input) | J2.7
IO_18 | Blue LED | | N/A
IO_19 | IO | SPI Slave MOSI | J2.6
IO_20 | IO | SPI Slave CSn | J2.5
IO_21 | Green LED | | N/A
IO_22 | Red LED | | N/A
IO_23 | IO | I2S Slave WCLK (frame) | J8.3
IO_24 | IO | I2S Slave DATA (dout) | J8.4
IO_25 | IO | | J3.9
IO_27 | IO | SPI Master CS2 | J2.2
IO_28 | PDM Data; to isolate, remove R13 | | J8.1
IO_29 | PDM CKO | | J8.2
IO_30 | IO | | J3.10
IO_31 | IO | I2S Slave CLK (input) | J8.5
IO_32 | IO | | J2.3
IO_33 | IO | | J2.4
IO_34 | SPI Master CLK | | J3.6
IO_36 | SPI Master MISO | | J3.4
IO_38 | SPI Master MOSI (flash) | | J3.5
IO_40 | IO | | N/A
IO_43 | IO | Interrupt output to Host | J2.9
IO_44 | IO | UART TX | J3.2
IO_45 | IO | UART RX | J3.3

### Connector J2

J2 | EOS S3 MCU IO | QFN Pin# | Function

1 VBAT
2 | IO_27 | 28 | IO; SPI Master CS2n
3 | IO_32 | 22 | IO; I2C bus 1 SDA
4 | IO_33 | 21 | IO; I2C bus 1 SCL
5 | IO_20 | 37 | SPI Slave SSn input; EOS S3 boot-strap
6 | IO_19 | 36 | SPI Slave MOSI input; EOS S3 boot-strap
7 | IO_17 | 42 | SPI Slave MISO output
8 | IO_16 | 40 | SPI Slave CLK input
9 | IO_43 | 7 | EOS S3 Interrupt output
10 | IO_3 | 2 | MC3635 Interrupt input
11 | IO_0 | 4 | I2C0 SCL
12 | IO_1 | 5 | I2C0 SDA

### Connector J3

J3 | EOS S3 MCU IO | QFN Pin# | Function

1 Ground
2 | IO_44 | 8 | S3 UART TX
3 | IO_45 | 9 | S3 UART RX
4 | IO_36 | 17 | SPI Master MISO input
5 | IO_38 | 16 | SPI Master MOSI output
6 | IO_34 | 20 | SPI Master CLK output
7 | IO_2 | 6 | IO
8 | IO_13 | 55 | IO
9 | IO_25 | 31 | IO
10 | IO_30 | 25 | IO
11 | ADC1 | 47 | ADC1 input
12 No Connect
13 Ground
14 No Connect
15 +3.3V
16 | SYS_RSTn | 41 | EOS S3 HW reset input

### Connector J8

J8 | EOS S3 MCU IO | QFN Pin# | Function
1 | IO_28 | 27 | PDM microphone Data
2 | IO_29 | 26 | PDM microphone CLK
3 | IO_23 | 33 | I2S Slave WCLK input
4 | IO_24 | 32 | I2S Slave DATA output
5 | IO_31 | 23 | I2S Slave CLK input
6 | IO_11 | 57 | IO
7 | IO_12 | 56 | IO
8 | IO_4 | 3 | IO
9 | IO_5 | 64 | IO
10 | IO_6 | 62 | User button input
11 | IO_7 | 63 | IO
12 | IO_8 | 61 | IO
13 | IO_10 | 59 | IO
14 No Connect
15 +3.3V
16 Ground

## Development connector

### EOS S3 MCU SWD connector

J6 | EOS S3 MCU IO | Function

1 +3.3V
2 | IO_15 | SWD IO
3 Ground
4 | IO_14 | SWD CLK
5 Ground
6 No Connect
7 No Connect
8 No Connect
9 Ground
10 | SYS_RSTn | Hardware Reset

### Boot-strap IO_19 & IO_20

- Install both shunts to use SWD Debugger for development
- Remove both shunts for boot-from-flash

Note: QuickFeather HDK board flash device must contain valid boot image for successful boot from flash.

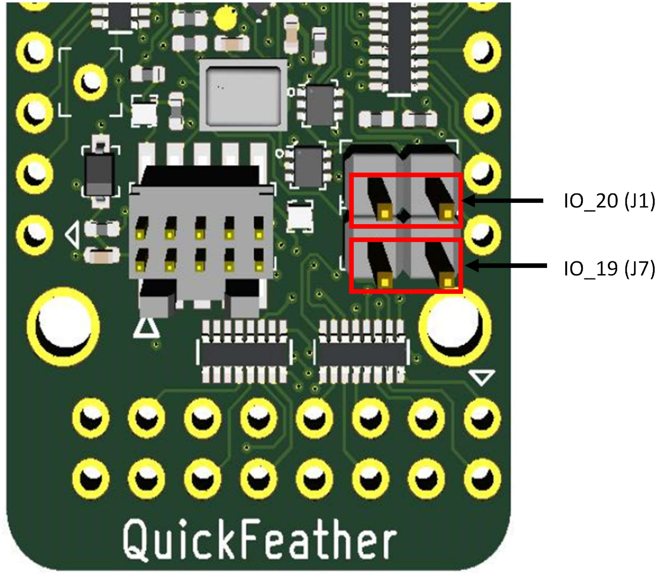
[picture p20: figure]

Figure 7: Boot strap J1 and J7

## QuickFeather HDK power supplies

There are two ways to provide power to the QuickFeather HDK: USB connector (J5) or Battery connector (J4). When both ports are connected at the same time, the USB power activates the battery charging circuit that provide charging current to the battery.
When using a rechargeable battery, the minimum input voltage will determine the maximum currents that the system needs to support. This is important when connecting additional peripherals to the QuickFeather HDK that also requires connection to +3.3V for supplies.

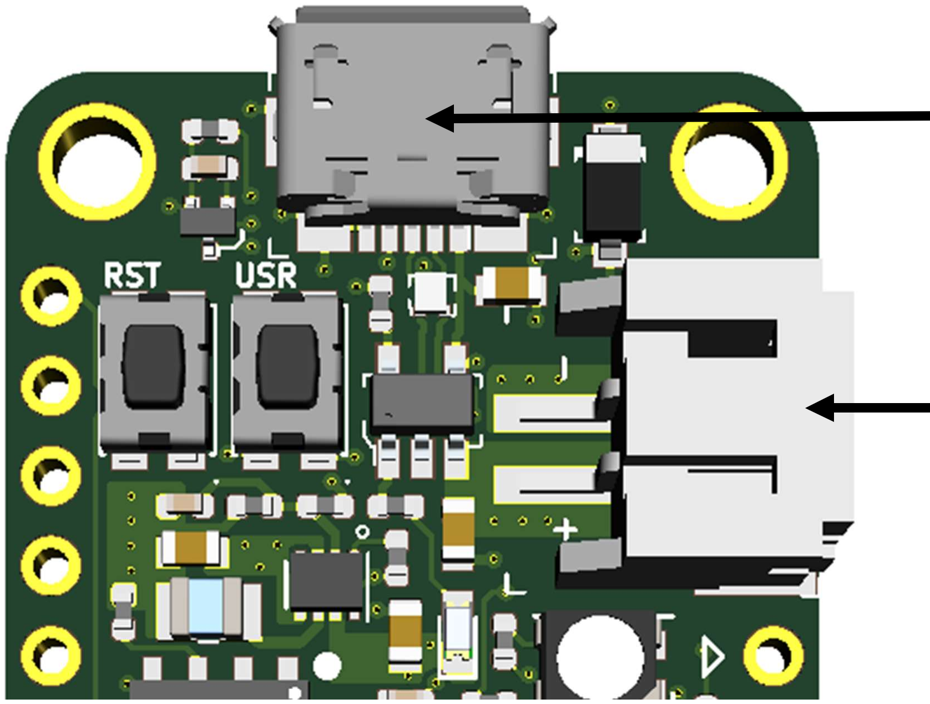
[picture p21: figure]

Figure 8: QuickFeather HDK Power inputs

## Connecting additional Peripherals to the QuickFeather HDK

QuickLogic’s QuickFeather supports direct connection to FeatherWing module (providing that the FeatherWing module has Stack Headers installed) via expansion connector J2 and J3. Refer to Adafruit web site for additional information on available FeatherWing modules.

### Sensor with I2C port

QuickFeather board supports connecting to sensor module with I2C slave interface via expansion connectors J2. QuickFeather I2C supports I2C Standard mode (100KHz) and Fast mode (400KHz). There are two I2C buses available:
- I2C0 bus: J2 pin 12 (SDA) and J2 pin 11 (SCL); the signals (SCL and SDA) are connected to 4.7KΩ pull-up resistor. This bus is shared with onboard I2C sensors: Accelerometer MC3635 (address 0x44h) and Pressure DPS310 (address 0x77h).
- I2C1 bus: J2 pin 3 (SDA) and J2 pin 4 (SCL); there is no pull up resistor on the I2C1 bus.
Steps to connect external I2C sensors to QuickFeather board:
- Ground connection
- Power connection (+3.3V supplies); check supply voltage level meeting connecting module requirement
- Connect SCL and SDA signals; check IO level (> +3.0V IO only)
- Keep connecting wires as short as possible
- Configure the I2C address to avoid address 0x44h (on-board ACCEL MC3635) and address 0x77h (on-board Pressure sensor DPS310)
- Check SCL and SDA rise time (< 1000 ns for Standard mode and < 300 ns for Fast mode)

Note: refer to I2C- bus specification for details (UM10204)

### Sensor with SPI Slave port

QuickFeather board supports connecting to sensor module with SPI slave interface via expansion connectors J2 and J3: SPI MASTER CLK (J3 pin 6), SPI MASTER MISO (J3 pin 4), SPI MASTER MOSI (J3 pin 5) and SPI MASTER SS2 (J2 pin 2). The maximum supported SPI clock frequency is 10MHz.
Steps to connect external SPI sensor to QuickFeather board:
- Ground connection
- Power connection (+3.3V supplies check supply voltage level meeting connecting module requirement
- Connect SPI MASTER signals; check IO level (> +3.0V IO only)
- Keep connecting wires as short as possible
- Check signal quality using scope

### PDM Microphones

Single PDM microphone

The on-board PDM microphone (Infineon IM69D130) is configured as left channel output (driving active data on falling edge of PDM CLK). QuickFeather supports external PDM microphone connection via expansion connector J8: PDM CLK (J8 pin 2) and PDM DATA (J8 pin 1).
Steps to connect one external PDM microphone to QuickFeather board:
- Ground connection
- Power connection (+3.3V supplies check supply voltage level meeting connecting module requirement
- Connect PDM CLK and PDM DATA signals; check IO level (> +3.0V IO only)
- Keep connecting wires as short as possible
- PDM microphone is configured as right channel microphone; the L/R signal or Channel signal is connected to VDD
- Check signal quality using scope

Two PDM microphones

To support two external PDM microphones configuration, it is required to disable the connection of the on-board PDM microphone.
QuickFeather supports external PDM microphone connection via expansion connector J8: PDM CLK (J8 pin 2) and PDM DATA (J8 pin 1).
Steps to connect two external PDM microphones to QuickFeather board:
- Ground connection
- Power connection (+3.3V supplies check supply voltage level meeting connecting module requirement
- Remove R13 (100Ω resistor)
- Connect PDM CLK and PDM DATA signals; check IO level (> +3.0V IO only)
- Keep connecting wires as short as possible; avoid star connection scheme (see figure below)
- Configure one PDM microphone as left channel and one PDM microphone as right channel
- Check signal quality using scope

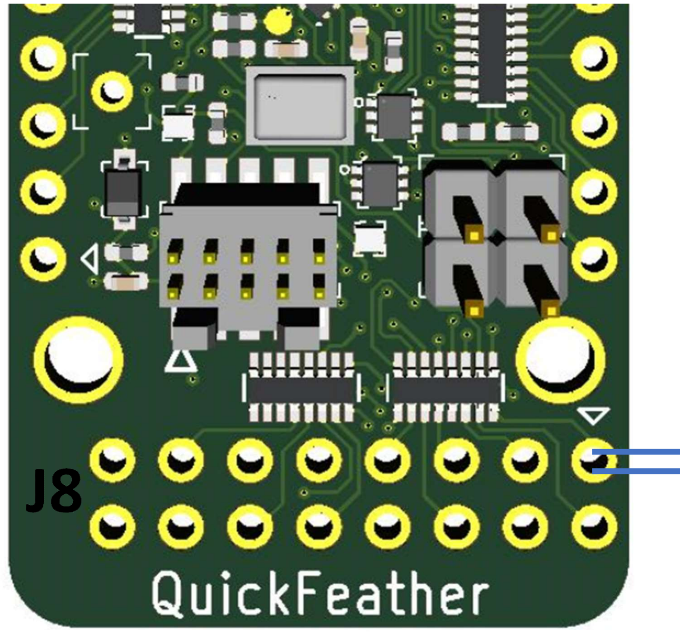
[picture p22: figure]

Figure 9: Microphones Wiring recommendation

## Revision

Version | Date | Revision
1.0 | June 2020 | First release.

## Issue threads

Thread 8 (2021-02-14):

Any plans for UF2 bootloader?

charkster, 2021-02-14:
Any plans to support a UF2 bootloader?
Also is the eFPGA configuration stored in on-die flash?
Thanks.

charkster, 2021-02-17:
I guess the EOS-S3 does not have a USB peripheral, which means it can not become a HID device (flash drive). This means no UF2 bootloader. There is also no flash memory on the EOS-S3 so the eFPGA configuration will be held in external Flash and then read into on-die ram.

Closed 2021-02-17.

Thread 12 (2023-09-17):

STEP file for PCB assembly is missing

paclogic, 2023-09-17:
Looking for the PCB Assembly as a STEP file in order to integrate.
I see that most if not all of the part 3D cad models as listed and looking for the completed assembly as a STEP file.
Thank you.

paclogic, 2023-10-08:
I saw that there is a 3D printed .STL file but really looking for the .STEP file to fold into my design. Not wanting to install KiCAD jsut to get the file. Posting would be helpful. Thank you again.

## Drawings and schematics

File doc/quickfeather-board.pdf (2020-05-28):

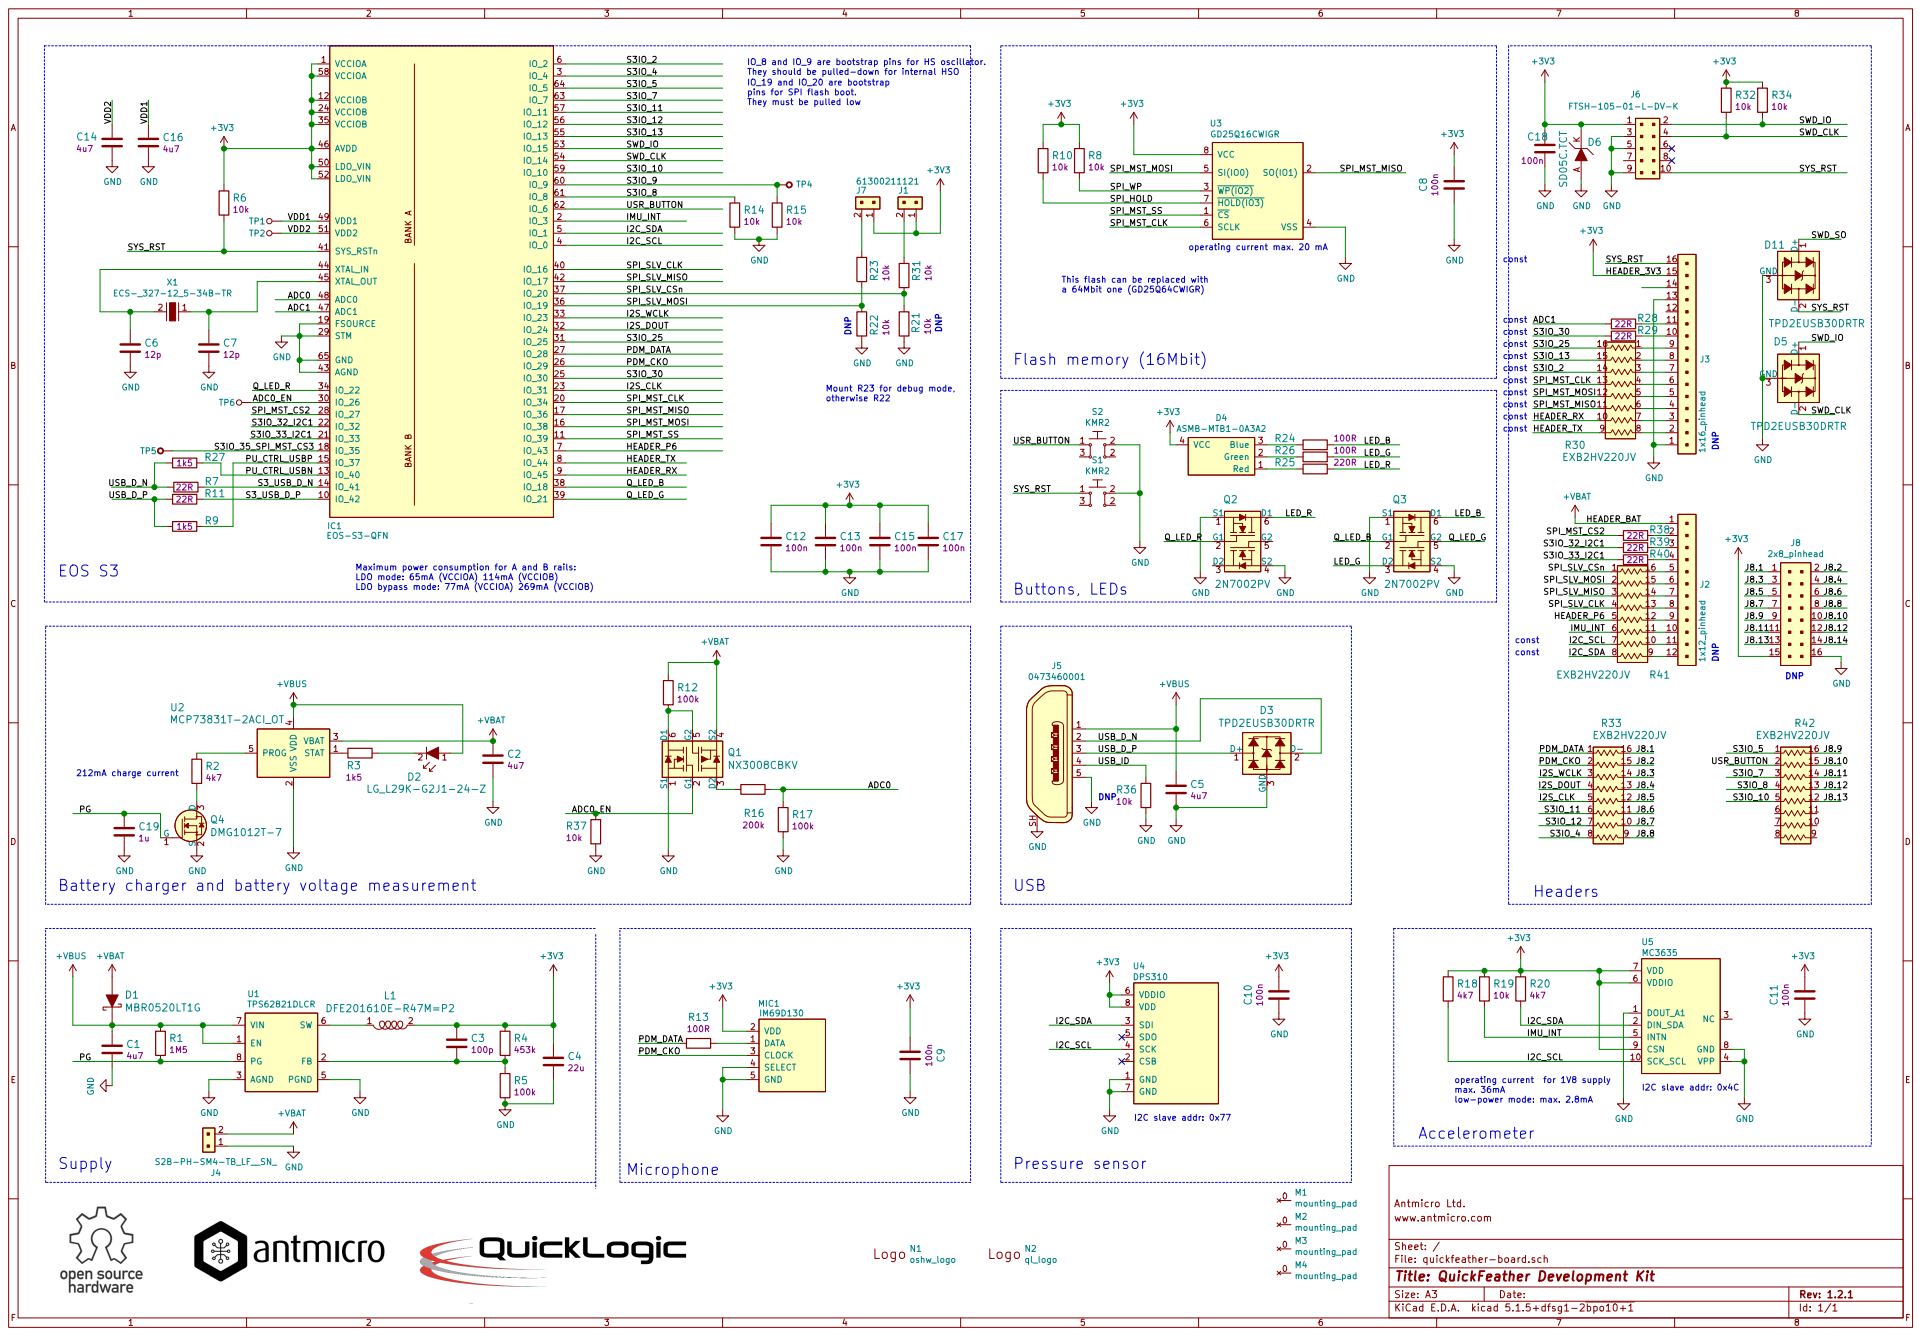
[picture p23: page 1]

IO_8 and IO_9 are bootstrap pins for HS oscillator.
They should be pulled-down for internal HSO DNP
IO_19 and IO_20 are bootstrap
pins for SPI flash boot.
They must be pulled low

const const const const const const const const const const Headers

operating current max. 20 mA DNP Mount R23 for debug mode, otherwise R22

This flash can be replaced with

const const operating current for 1V8 supply max. 36mA

Maximum power consumption for A and B rails:
LDO mode: 65mA (VCCIOA) 114mA (VCCIOB)

Battery charger and battery voltage measurement

low-power mode: max. 2.8mA

File: quickfeather-board.sch Sheet: / www.antmicro.com

Id: 1/1 Title: QuickFeather Development Kit

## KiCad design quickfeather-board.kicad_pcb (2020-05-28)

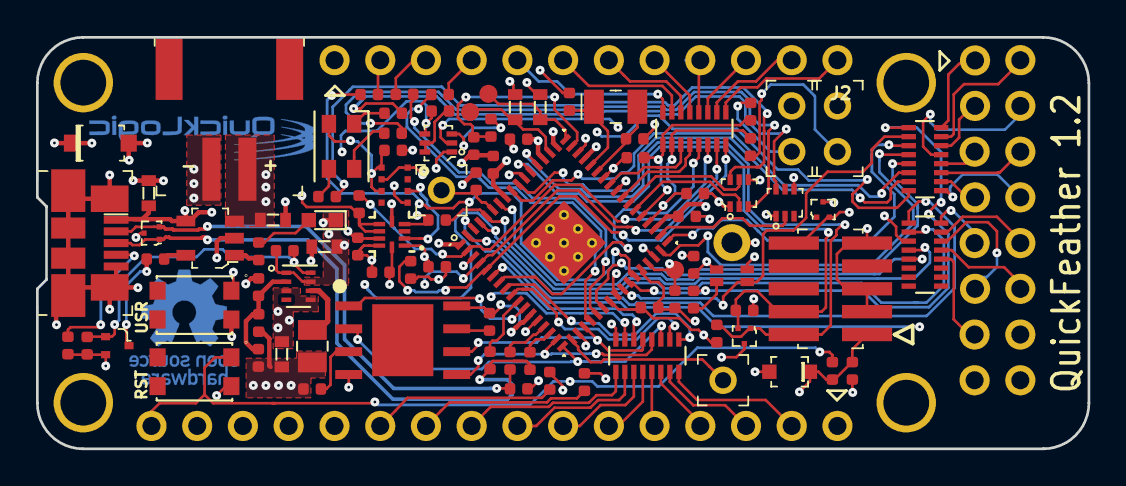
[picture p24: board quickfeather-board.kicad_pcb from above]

Board: 4 copper layers, 58.4 x 22.9 mm, 101 parts (0 on the bottom side), 114 nets.

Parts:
C1, C2, C5, C14, C16: C_4u7_0603; 0603-cap
C3: C_100p_0402; 0402-cap
C4: C_22u_0603; 0603-cap
C6, C7: C_12p_0402; 0402-cap
C8, C9, C10, C11, C12, C13, C15, C17, C18: C_100n_0402_6V3; 0402-cap
C19: C_1u_0402; 0402-cap
D1: MBR0520LT1G; SOD-123
D2: LG_L29K-G2J1-24-Z; LED_0603
D3, D5, D11: TPD2EUSB30DRTR; SOT-3
D4: ASMB-MTB1-0A3A2; LED-PLCC4_3.2x2.8mm_B
D6: SD05C.TCT; SOD-323-SD05
IC1: EOS-S3-QFN; QFN-64_8.5x8.5_EOS
J1, J7: 61300211121; PinHeader_1x2_P2.54_Drill0.9mm
J2: 1x12_pinhead
J3: 1x16_pinhead
J4: S2B-PH-SM4-TB_LF__SN_; PinHeader_2x1mm_P2mm_SMD_RA
J5: 0473460001; USB_Micro_B_Female_0473460001
J6: FTSH-105-01-L-DV-K; PinHeader_2x5_P1.27_SMD
J8: 2x8_pinhead
L1: DFE201610E-R47M=P2; 0806
M1, M2, M3, M4: mounting_pad; MPAD
MIC1: IM69D130
N1: oshw_logo; oshw-logo
N2: ql_logo; LOGO
Q1: NX3008CBKV; SOT-563
Q2, Q3: 2N7002PV; SOT-563
Q4: DMG1012T-7; SOT-523
R1: R_1M5_0402; 0402-res
R2, R18, R20: R_4k7_0402; 0402-res
R3, R9, R27: R_1k5_0402; 0402-res
R4: R_453k_0402; 0402-res
R5, R12, R17: R_100k_0402; 0402-res
R6, R8, R10, R14, R15, R19, R21, R22, R23, R31, R32, R34, R36, R37: R_10k_0402; 0402-res
R7, R11, R28, R29, R38, R39, R40: R_22R_0402; 0402-res
R13, R24, R26: R_100R_0402; 0402-res
R16: R_200k_0402; 0402-res
R25: R_220R_0402; 0402-res
R30, R33, R41, R42: EXB2HV220JV; R_Array_Convex_8x0602
S1, S2: KMR2; SW_SPST_4.2x2.8
TP1, TP2, TP6: TP_SMD1MM; Testpoint_smd_1mm
TP4, TP5: TP_THT; Testpoint_THT_Drill0.9mm
U1: TPS62821DLCR; QFN-8_2x1mm
U2: MCP73831T-2ACI_OT; SOT-753
U3: GD25Q16CWIGR; GD25Q16CWIG
U4: DPS310; PG-VLGA-8-2
U5: MC3635
X1: ECS-_327-12_5-34B-TR; SMD-2_3.2x1.5mm

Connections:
+3V3: C3.1, C4.1, C8.1, C9.2, C10.1, C11.1, C12.1, C13.1, C15.1, C17.1, C18.1, D4.4, D6.K, IC1.1, IC1.12, IC1.24, IC1.35, IC1.46, IC1.50, IC1.52, IC1.58, J1.1, J3.15, J6.1, J7.1, J8.15, L1.2, MIC1.2, R4.1, R6.1, R8.1, R10.1, R18.1, R19.1, R20.1, R32.1, R34.1, U3.8, U4.6, U4.8, U5.6, U5.7, U5.9
+VBAT: C2.1, D1.A, J2.1, J4.2, Q1.4, R12.1, U2.3
+VBUS: C1.1, C5.1, D1.K, D2.1, J5.1, R1.1, U1.1, U1.7, U2.4
/ADC0: IC1.48, R16.1, R17.1
/ADC0_EN: IC1.30, Q1.2, R37.1, TP6.1
/ADC1: IC1.47, R28.1
/HEADER_P6: IC1.7, R41.5
/HEADER_RX: IC1.9, R30.10
/HEADER_TX: IC1.8, R30.9
/I2C_SCL: IC1.4, R18.2, R41.7, U4.4, U5.10
/I2C_SDA: IC1.5, R20.2, R41.8, U4.3, U5.2
/I2S_CLK: IC1.23, R33.5
/I2S_DOUT: IC1.32, R33.4
/I2S_WCLK: IC1.33, R33.3
/IMU_INT: IC1.2, R19.2, R41.6, U5.5
/J8.1: J8.1, R33.16
/J8.2: J8.2, R33.15
/J8.3: J8.3, R33.14
/J8.4: J8.4, R33.13
/J8.5: J8.5, R33.12
/J8.6: J8.6, R33.11
/J8.7: J8.7, R33.10
/J8.8: J8.8, R33.9
/J8.9: J8.9, R42.16
/J8.10: J8.10, R42.15
/J8.11: J8.11, R42.14
/J8.12: J8.12, R42.13
/J8.13: J8.13, R42.12
/LED_B: Q3.6, R24.1
/LED_G: Q3.3, R26.1
/LED_R: Q2.6, R25.1
/PDM_CKO: IC1.26, MIC1.3, R33.2
/PDM_DATA: IC1.27, R13.2, R33.1
/PG: C19.1, Q4.1, R1.2, U1.8
/PU_CTRL_USBN: IC1.13, R27.1
/PU_CTRL_USBP: IC1.15, R9.1
/Q_LED_B: IC1.38, Q3.2
/Q_LED_G: IC1.39, Q3.5
/Q_LED_R: IC1.34, Q2.2
/S3IO_2: IC1.6, R30.14
/S3IO_4: IC1.3, R33.8
/S3IO_5: IC1.64, R42.1
/S3IO_7: IC1.63, R42.3
/S3IO_8: IC1.61, R14.1, R42.4
/S3IO_9: IC1.60, R15.1, TP4.1
/S3IO_10: IC1.59, R42.5
/S3IO_11: IC1.57, R33.6
/S3IO_12: IC1.56, R33.7
/S3IO_13: IC1.55, R30.15
/S3IO_25: IC1.31, R30.16
/S3IO_30: IC1.25, R29.1
/S3IO_32_I2C1: IC1.22, R39.2
/S3IO_33_I2C1: IC1.21, R40.2
/S3IO_35_SPI_MST_CS3: IC1.18, TP5.1
/S3_USB_D_N: IC1.14, R7.1
/S3_USB_D_P: IC1.10, R11.1
/SPI_HOLD: R10.2, U3.7
/SPI_MST_CLK: IC1.20, R30.13, U3.6
/SPI_MST_CS2: IC1.28, R38.2
/SPI_MST_MISO: IC1.17, R30.11, U3.2
/SPI_MST_MOSI: IC1.16, R30.12, U3.5
/SPI_MST_SS: IC1.11, U3.1
/SPI_SLV_CLK: IC1.40, R41.4
/SPI_SLV_CSn: IC1.37, R21.1, R31.1, R41.1
/SPI_SLV_MISO: IC1.42, R41.3
/SPI_SLV_MOSI: IC1.36, R22.2, R23.1, R41.2
/SPI_WP: R8.2, U3.3
/SWD_CLK: D5.2, IC1.54, J6.4, R32.2
/SWD_IO: D5.1, IC1.53, J6.2, R34.2
/SYS_RST: D11.2, IC1.41, J3.16, J6.10, R6.2, S1.1
/USB_D_N: D3.2, J5.2, R7.2, R27.2
/USB_D_P: D3.1, J5.3, R9.2, R11.2
/USB_ID: J5.4, R36.1
/USR_BUTTON: IC1.62, R42.2, S2.1
/VDD1: C16.1, IC1.49, TP1.1
/VDD2: C14.1, IC1.51, TP2.1
GND: C1.2, C2.2, C4.2, C5.2, C6.2, C7.2, C8.2, C9.1, C10.2, C11.2, C12.2, C13.2, C14.2, C15.2, C16.2, C17.2, C18.2, C19.2, D3.3, D5.3, D6.A, D11.3, IC1.19, IC1.29, IC1.43, IC1.65, J3.1, J3.13, J4.1, J5.5, J5.SH, J6.3, J6.5, J6.9, J8.16, MIC1.4, MIC1.5, Q1.1, Q2.1, Q2.4, Q3.1, Q3.4, Q4.2, R5.2, R14.2, R15.2, R17.2, R21.2, R22.1, R36.2, R37.2, S1.2, S2.2, U1.3, U1.5, U2.2, U3.4, U4.1, U4.7, U5.1, U5.4, U5.8
unnamed: C3.2, R4.2, R5.1, U1.2
unnamed: C6.1, IC1.44, X1.2
unnamed: C7.1, IC1.45, X1.1
unnamed: D2.2, R3.1
unnamed: D4.1, R25.2
unnamed: D4.2, R26.2
unnamed: D4.3, R24.2
unnamed: J1.2, R31.2
unnamed: J2.2, R38.1
unnamed: J2.3, R39.1
unnamed: J2.4, R40.1
unnamed: J2.5, R41.16
unnamed: J2.6, R41.15
unnamed: J2.7, R41.14
unnamed: J2.8, R41.13
unnamed: J2.9, R41.12
unnamed: J2.10, R41.11
unnamed: J2.11, R41.10
unnamed: J2.12, R41.9
unnamed: J3.2, R30.8
unnamed: J3.3, R30.7
unnamed: J3.4, R30.6
unnamed: J3.5, R30.5
unnamed: J3.6, R30.4
unnamed: J3.7, R30.3
unnamed: J3.8, R30.2
unnamed: J3.9, R30.1
unnamed: J3.10, R29.2
unnamed: J3.11, R28.2
unnamed: J7.2, R23.2
unnamed: L1.1, U1.6
unnamed: MIC1.1, R13.1
unnamed: Q1.3, R16.2
unnamed: Q1.5, Q1.6, R12.2
unnamed: Q4.3, R2.2
unnamed: R2.1, U2.5
unnamed: R3.2, U2.1

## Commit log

2019-12-27 Initial set of files for Quick Feather board
    [quicklogic-quick-feather-board.csv, quicklogic-quick-feather-board.kicad_pcb, quicklogic-quick-feather-board.sch]
2019-12-27 More files for QuickFeather development board
2020-04-18 Update with latest Quick Feather Design files
    [quick-feather-board-BOM-populated.csv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]
2020-04-18 Remove obsolete files
    [quicklogic-quick-feather-board.kicad_pcb]
2020-05-14 Sync to Revision 1.2.1
    [quick-feather-board-BOM-populated.csv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]
2020-05-28 Update with: 1. New 3D models 2. Add UserGuide 3. Update schematic EOS S3 body naming 4. Update board package
    [quickfeather-board-B_Adhes.gbr, quickfeather-board-B_CrtYd.gbr, quickfeather-board-B_Fab.gbr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]
2020-05-29 Update for J8 Pin 14 to NC
2020-06-04 1. Archive rev 1.0 userguide and binaries for boards ship prior to 2020-jun-15 2. Update User Guide for R1.1 3. Add folder to contain default binaries in programmed flash
2020-10-05 Streamline readme with getting-started structure
    Add quick-reference details for users to refer to connect a USB-UART cable to the QF board.
